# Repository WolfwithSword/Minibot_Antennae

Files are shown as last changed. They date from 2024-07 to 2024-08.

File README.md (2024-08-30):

# Minibot_Antennae
Micropython-ESP32 code for custom antennae control based on Ellie Minibot's OC's antennae. WiFi and BLE servers included for control.

Three green LEDs will be controlled by monitoring a connected LiPo battery voltage (not capacity!)

Two LEDs (one on each side) on the antennae bulbs will be PWM controlled in a fading sequence. These can be synced or toggled on/off individually via various control endpoints and services. By default on boot, they will be synced ON.

By default, WiFi Mode is enabled.

### Demo Video:

Demo Video (https://youtu.be/qy43_1V1VM8 "Demo Video")

https://youtu.be/qy43_1V1VM8 

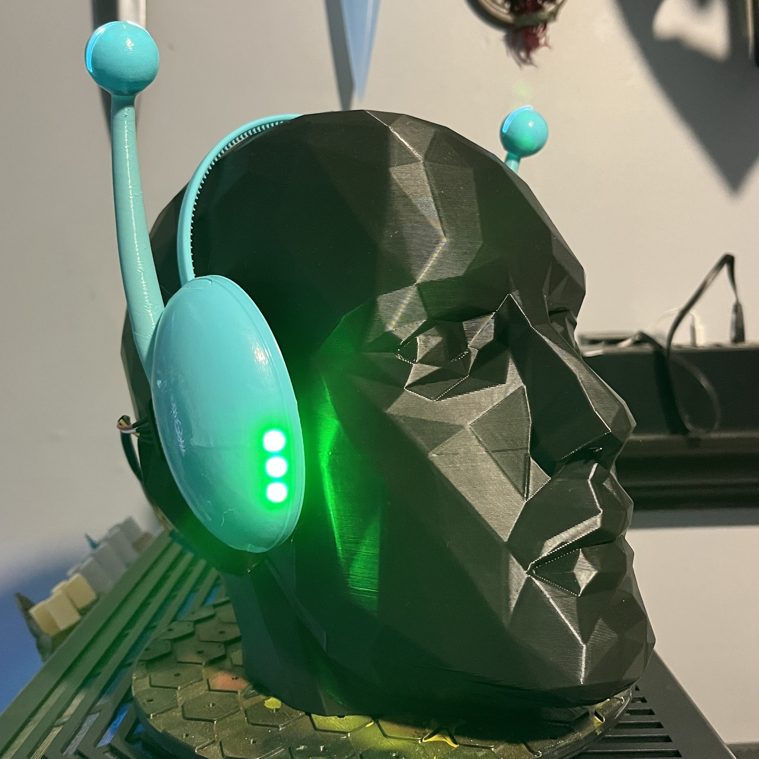
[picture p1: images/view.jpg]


# Setup

## MicroPython

- Download [esptool](https://github.com/espressif/esptool)
- Flash your board
  - Replace below command with the appropriate COM# port you plugged in to for the board 
  - `./esptool.exe --port COM# erase_flash`

- Flash with MicroPython
  - Download latest for [ESP32](https://micropython.org/download/ESP32_GENERIC/)
  - Replace COM# with yours below, as well as correct MicroPython binary downloaded
  - `./esptool.exe --chip esp32 --port COM# --baud 460800 write_flash -z 0x1000 .\ESP32_GENERIC-20240602-v1.23.0.bin`

## IDE

I recommend using [Thonny](https://github.com/thonny/thonny)

You can easily download the dependencies to the board through it.

## Dependencies

- [aioble](https://github.com/micropython/micropython-lib/tree/master/micropython/bluetooth/aioble)
  - Make sure it's the micropython lib
  
## Install

Simply save each of the files in `/src/*` to the root of the board (do not include the src folder itself). Preserve all filenames

Modify `config.json` as required. These will be the default settings on every boot.

Note: This file may be written to, but it will only ever change "mode"

## Materials

See [parts](https://github.com/WolfwithSword/Minibot_Antennae/tree/main/parts)  folder for details

You can find the files also on [Printables](https://www.printables.com/model/971520-ellie-minibot-antennae)

Note: The choice for the "FireBeetle" ESP32 controller was mostly because of the battery plug being on the side and expandability... But the fact it's a "Beetle" is a big bonus I only realized after!

Most of the design from materials, code, and components was chosen to be more accessible and customizable/tinkerable.

# Usage

## Configuration

```json
{
    "wifi": {
        "name": "minibot_AT", // Access point SSID and hostname (both in AP mode and connected to WiFi)
        "ap_password": "eBot4do8", // Access point Password. Please Change
        "max_connections": 2, // Max number of listeners allowed for the socket control server
        "port": 8080 // Port for accessing the socket control server
    },
    "ble": {
        "name": "minibot_AT", // Bluetooth device name
        "uuid": "6094935a-ba8d-4fbb-9150-904e3244610b", // BLE Service Advertised UUID
        "poll_time": 5 // How often to update BLE read-only sensors
    },
    "mode": 1, // Which mode to boot in.
    "pwm": {  // PWM pins are the Antennae bulbs only.
        "frequency": 500, // Frequency of PWM pins. 
        "delay": 0.03, // Delay between fading steps. Min 0.01.
        "off_time_multiplier": 1.2, // Multiplied by delay for time to stay fully off during PWM cycle
        "on_time_multiplier": 4.0, // Multiplied by delay for time to stay fully on during PWM cycle
        "step": 32 // Step count from 0-1024 and 1024-0 for LED brightness in between delays. Min 8
    },
    "leds": { // If true, the LED can be active.
        "green1": true, 
        "green2": true,
        "green3": true,
        "left": true,
        "right": true,
        "sync_sides": true
    },
    "poll_time": 2 // Poll time to check for battery voltage in main loop.
}
```

Mode values:
  - 0: None
    - No WiFi Socket or BLE Server active. Can only set with direct access to the board and changing the config on-board.
  - 1: WiFi
    - Enables WiFi. Will create an AP to connect to and configure a 2.4Ghz WiFi to connect to and save details for.
    - When successfully connected to a WiFi, will create a socket server at the specified port
  - 2: BLE
    - Enables the BLE server

## WiFi

### Setup

If you can't find the IP address, it will have the hostname configured as "name" in the "wifi" section of the configuration. By default, this will mean it has a hostname of `minibot_AT`, may work as `minibot_AT.local`.

When in AP mode to setup a network connection, hostname should work but if not, the setup page usually will be available at `192.168.4.1` when connected to it.

If setting up multiple, please change the hostname and maybe the password for security.

### Alternative Setup

If you don't have a second device to setup wifi with, you can manually setup WiFi connection via a file

In the root of the board, create a `wifi.dat` file and on the first line put in `SSID_NAME;SSID_PASSWORD` then add a blank empty newline after it

It must be a 2.4ghz SSID. Also for setting up multiple, you can do a new one on each line.

### Endpoints
  - GET
    - /, /data
      - Returns JSON with **battery_voltage** and **uptime_s** 
        - Example`{"battery_voltage": 4.135, "uptime_s": 155.984}`
    - /restart
      - Hard-restart the board
    - /mode/1
      - Tells you that you're dumb cause you're already in WiFi Mode
    - /mode/2
      - Switch to BLE and restart board
    - /leds/right/off
      - Turn OFF Right Antenna LED
    - /leds/right/on
      - Turn ON Right Antenna LED
    - /leds/left/off
      - Turn OFF Left Antenna LED
    - /leds/left/on
      - Turn ON Left Antenna LED
    - /leds/sync/off
      - Turn OFF Antenna LEDs (Sync)
    - /leds/sync/on
      - Turn ON Antenna LEDs (Sync)
    - All other endpoints result in HTTP 404. All previous in HTTP 200
    - /leds?delay=####
      - Set the PWM Delay to this value in seconds. Accepts floats. E.G., `?delay=1` = 1s, `?delay=0.02` = 200ms
      - Can pass in `delay=default`
      - Min value = 0.012, Max value = 10, default 0.03 (without modification)
    - /leds?steps=####
      - Set the PWM Steps to this whole number value. E.G., `?steps=32`, `?delay=0.03&steps=32`
      - Can pass in `steps=default`
      - Min value = 8, Max value = 128, default 32 (without modification)

## BLE

### Services & Characteristics
  
  - Battery Voltage: **0x2BF0**
  - Uptime Sensor (Seconds): **0x183F**
  - Switch Modes: **0x04C3**
    - 1 *uint8*: Switch to WiFi and restart board
    - All other inputs ignored
  - LED Control: **0x77DA**
    - 0 *uint8* - Turn OFF Left Antenna LED
    - 1 *uint8* - Turn ON Left Antenna LED
    - 2 *uint8* - Turn OFF Right Antenna LED
    - 3 *uint8* - Turn ON Right Antenna LED
    - 4 *uint8* - Turn OFF Antenna LEDs (Sync)
    - 5 *uint8* - Turn ON Antenna LEDs (Sync)
    - All other inputs ignored
  - Set PWM Delay: **0x77DB**
    - Milliseconds *uint16 big endian* - Set PWM Delay, accepts milliseconds, not seconds.
    - Value of 0 will set it to the default of 0.03
  - Set PWM Steps: **0x77DC**
    - Steps *uint8* - Set the PWM Steps, accepts whole numbers from 0 to 128
    - Value of 0 will set it to default of 32.
    
## Notes

You can remotely configure the PWM parameters for the bulb LEDs with WiFi or BLE. Delay will update as soon as the old delay time has elapsed so near-instant. Step will update only after a step up or step down cycle has completed for an up-cycle or down-cycle.

For example, you can adjust the delay (and steps value, but delay is preferred) remotely based on other values. One use case may be to sync entering/exiting ranges of a heart rate monitor's BPM to push different delay values, or perhaps rate ranges of any other activity.

Examples for WiFi control of PWM adjustments:

  - For a really fast cycle, I recommend `?delay=0.012&steps=64` or `?delay=0.012&steps=128` (fastest)
  - Default would be `?delay=0.03&steps=32` or `?delay=default&steps=default`

The green LEDs are not controllable as they work as battery indicators. Rather than measure current or capacity which would be more accurate, I did not have time to plot the graph to tell capacity at specific voltages as it will be battery dependant, so it is at arbitrary battery voltage amounts. A 3.7v lipo at full charge is near 5v, and will stay around 4.2v for a very long time, and when there is approx 10% and 20% ish or less remaining it will turn off the top led's. It may shut down all processing and threads shortly after reaching single-LED mode if there is not enough power left (roughly when it gets to 3.2v or below, and will full stop at under 3v). 

When there is only the last LED left one, it is possible the board will go into a deep sleep and stop all threads (no WiFi, BLE, or PWM Fades). In this mode it will keep that last LED lit for approximately 2 hours.

ALL values are reset to default when the board is restarted or switching modes. Only the value of the mode is retained after restarting, and is written to the config file.

If for whatever reason it is stuck and not connecting to WiFi or threads got stuck like from being in deepsleep and back up again after charging, just quickly disconnect the pogo connectors when it's not charging for a second. This also acts as the power switch - there is none, just unplug one side of the pogo wire.

When enabling an individual LED while Sync is on, it will disable Sync and the other LED will need to be turned on separately if you want both unsynced. Turning off Sync when sync is not enabled will do nothing. Turning on Sync will restart both lights.

When using the 1100maH battery, it will last roughly 17 hours on a full charge (charging ~1h at 2A), but can last easily 11-13 hours on fullish charge (~20-30min at 2A). Battery capacity is not measured but rather voltage levels are used as ranges to signal the three green LEDs. Just because all are lit up does not mean it is fully charged by far.

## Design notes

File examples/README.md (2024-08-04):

# Example Integrations

## Pulsoid BPM Control

`pulsoid_bpm_control.py` can be run on a desktop with python (required dependencies: `websocket-client` and `requests`)

Configuration required for a websocket that provides heartrate in terms of whole numbers, such as from Pulsoid. Comments in the code describe how you can get the websocket URL if you do not know.

Additional config may be needed for the hostname and port of the Antennae instance in **WiFi Mode**.

This script will listen for the BPM reported by the websocket connection and depending on the ranges it is in, will adjust the PWM Fade/Pulse rate of the antennae tips.

Unless modified, default settings are: 

Delay is in seconds

- BPM <= 75: Default delay (0.03), Default steps (32)
- BPM 75-90: Delay 0.02, Default steps (32)
- BPM 90-100: Delay 0.02, Steps 64
- BPM 100-120: Delay 0.12, Steps 64
- BPM 120+: Delay 0.12, Steps 128

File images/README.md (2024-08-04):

# Minibot_Antennae Media

## Completed





Demo Video (https://youtu.be/qy43_1V1VM8 "Demo Video")

## Bits n Bobs

### Models

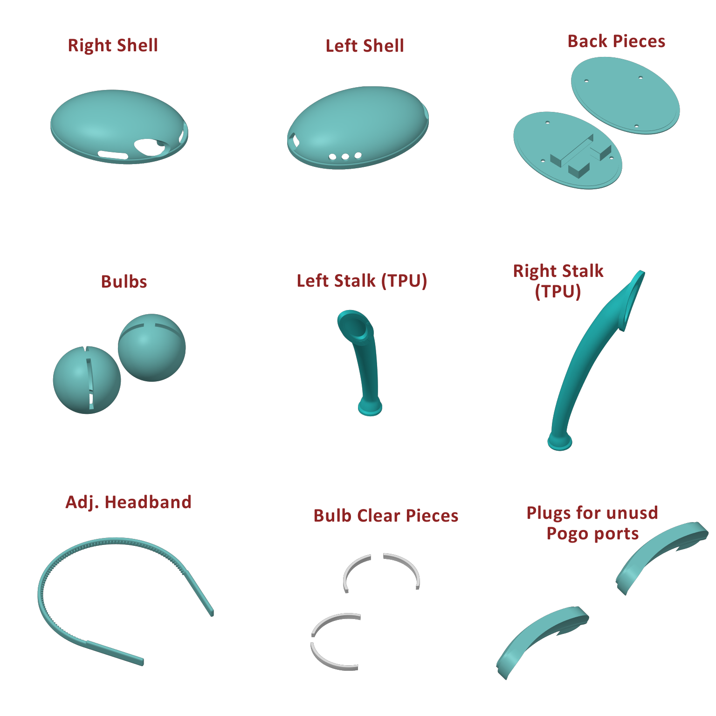
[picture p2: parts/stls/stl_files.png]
STL Images


### Headband 

Headband is adjustable with 6 holes for the screw placement, which doubles as part of the assembly. It can also rotate freely if loosened a bit, then simply tightened for a better fit.

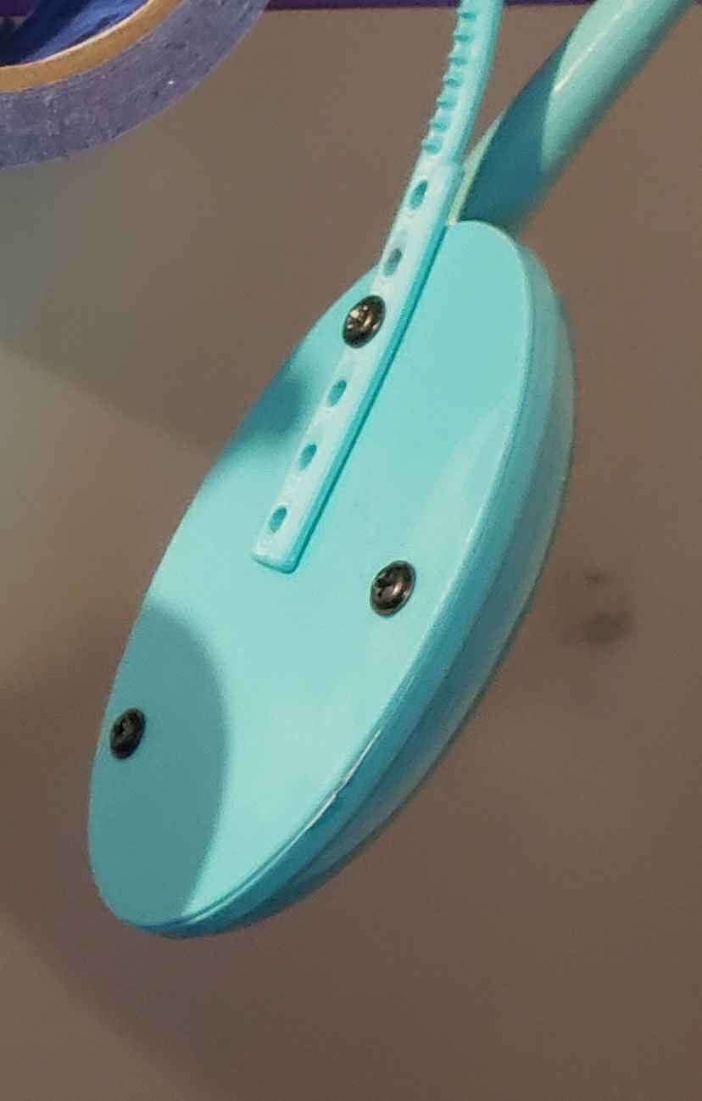
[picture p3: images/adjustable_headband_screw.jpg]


### Internals & Diagrams

The internals of the controller half (Right side) are a touch messy (I couldn't find my thinner wire, had to redo half of the solders because of broken pins while debugging a grounding wire issue, etc etc). The hot glue is purely for strain relief and to keep LEDs in place in case they wear down their friction fit.

"If it works it works" > "Hopes and dreams" 

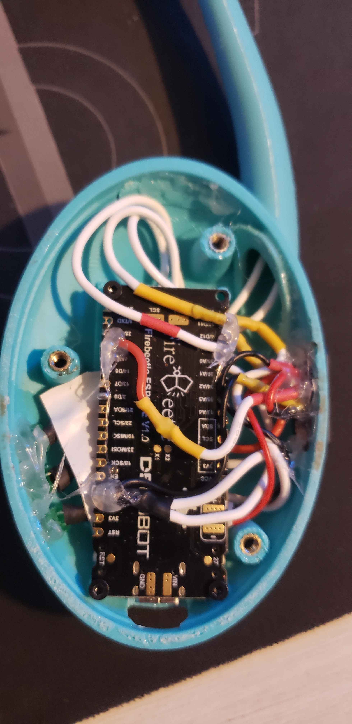
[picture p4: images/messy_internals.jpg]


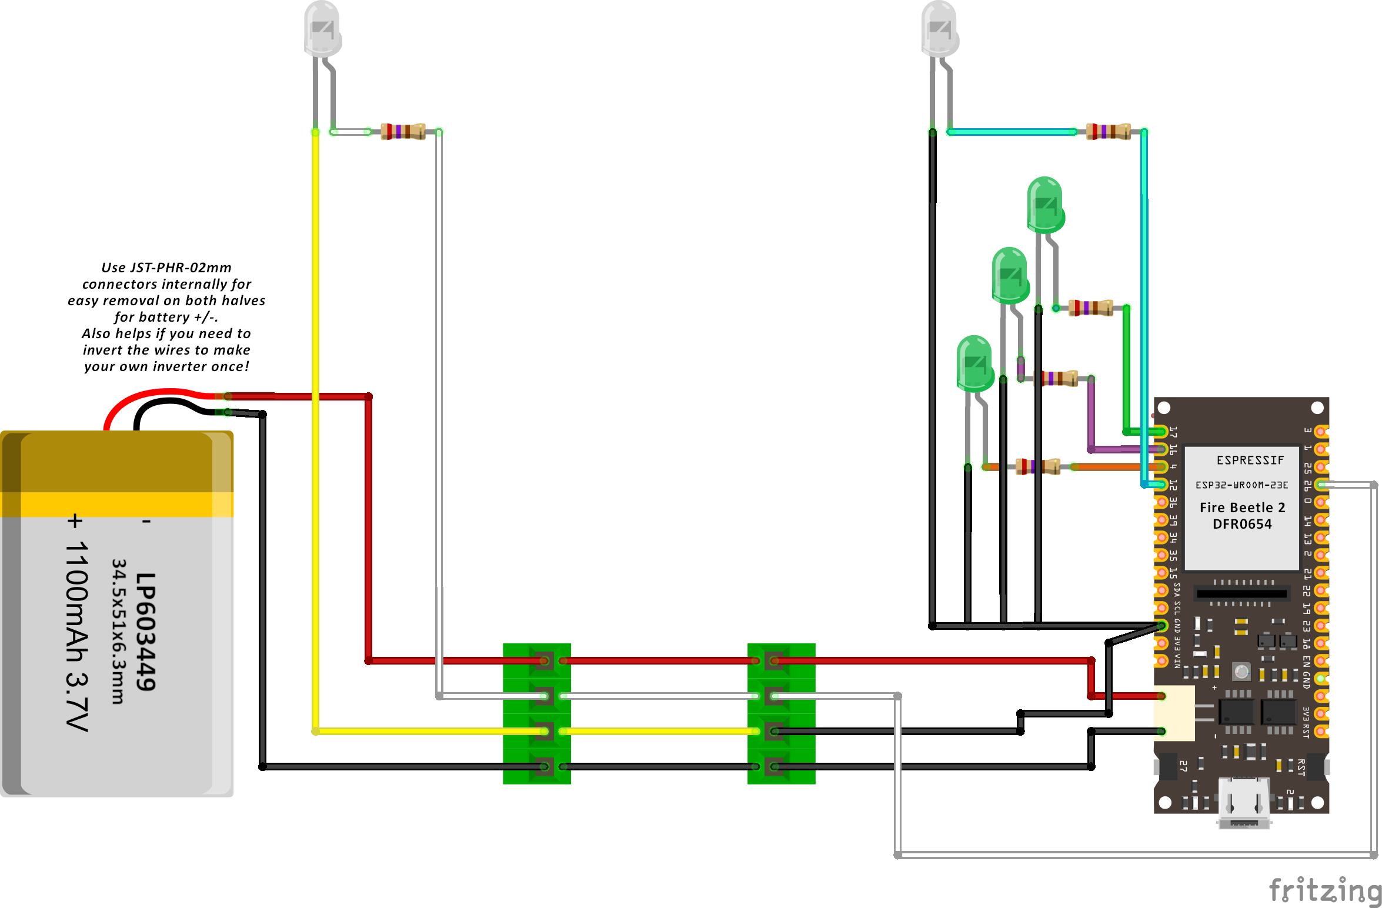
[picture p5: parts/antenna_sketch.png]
Schematic


### BLE Preview

Just a preview of some of the BLE characteristics/services for control using nRF Connect

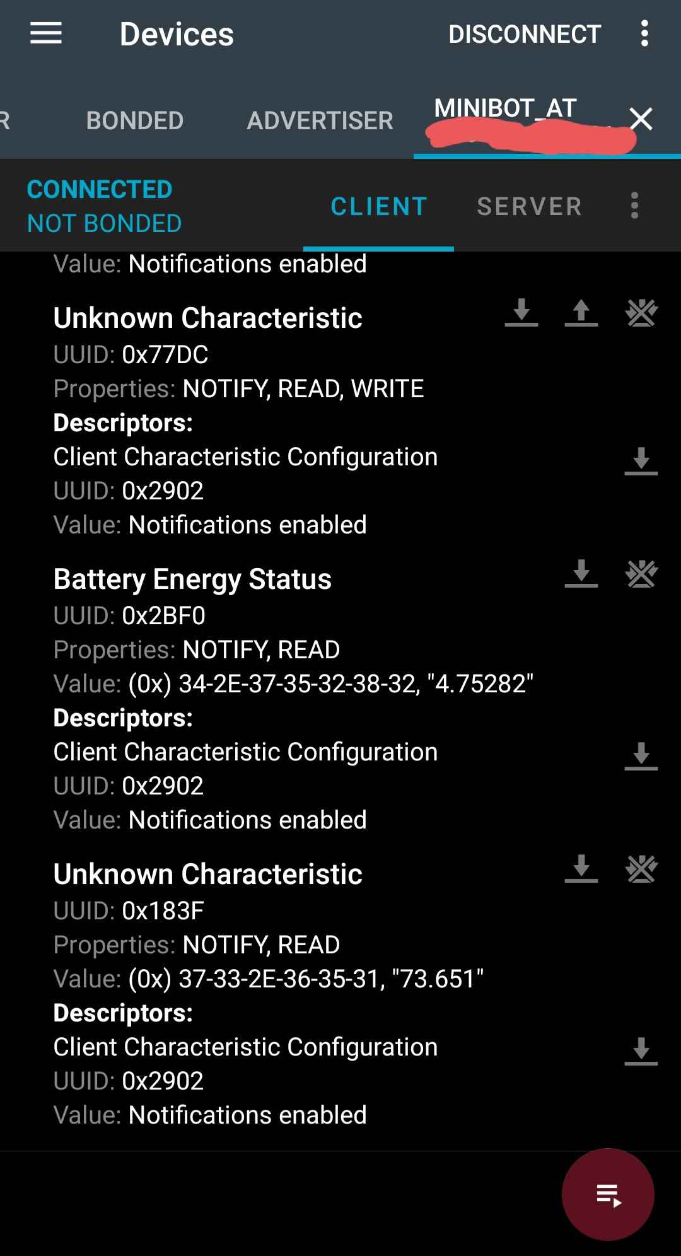
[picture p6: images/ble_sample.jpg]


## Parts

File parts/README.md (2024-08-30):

You can find the files also on [Printables](https://www.printables.com/model/971520-ellie-minibot-antennae)

# STLs

- Stalks: tpu_left_stalk.stl, tpu_right_stalk.stl
- Bulbs: abs_left_bulb, abs_right_bulb, abs_clear_left_bulb_light.stl, abs_clear_right_bulb_light.stl
- Headband: headband.stl
- Left Shell: abs_left_backing.stl, abs_left_shell.stl
- Right Shell: abs_right_backing.stl, abs_right_shell.stl
  - Note: The screw alignment for the ESP32 board is *not* perfect, despite using references. As such, when screwing in with M2 screws, may only fit 3 screws and one may be at an angle. Prioritize the front near the USB-C port.
- Misc: abs_top_plugs.stl, abs_side_plugs.stl
  - The plugs are for plugging the holes for where you do *not* use the pogo connector inserts.

# BOM

This is not my best BOM, made in rush

- ESP32 Board DFR0654. [Digikey](https://www.digikey.ca/en/products/detail/dfrobot/DFR0654/13978504),  [dfrobot](https://www.dfrobot.com/product-2195.html)
  - Any other can do, and can probably be swapped for a smaller one with a separate charge shield/circuit for battery. The one linked simply fit the best, had decent processing power and memory, and had the built in battery port and charger on the side instead of the front.
  - Chosen for expandability. If using another board, there are no guarantees as to the code working fully in case lack of processing or memory.
  - This project can use both BLE and WiFi servers, but the config does allow to disable both if you want just default settings.
- LiPo Battery
  - [3.7v 1100mAh, 34.5x51x6.3mm (WxLxH)](https://amzn.to/3zZs4OB)
  - If using the one from the link, you *MAY* need to swap the pwr and gnd leads. Make sure before hooking up to board AND before hooking up to JST port/wires. Good idea to make an inverter wire so it isn't permanent.
  - For alternatives, size the slot fits is mentioned above. If loose, please pad to make sure it does not come out during use. Capacity can be any, 1100mAh will last between 12-18 hours roughly.
- Screws
  - 4x M2 8-12mm (For ESP32, no heatset inserts, direct to plastic)
  - 2x M3 14mm 
  - 4x M3 12mm (6x if not using headband, possibly will work for all 6 anyways. Then no need for 14mm. I just used all 14mm and cut 4 of em)
- 6x M3 x4mm Heatset inserts
- Resistors
  - 5x 270ohm
- LEDs [Basic kit](https://amzn.to/4fkcopn)
  - 3x Green 5mm (Green plastic shell, so it is still green when off)
  - 2x White or Yellow (your preference) 5mm
- JST-PHR-02 Female and Male connectors (1 pair). [Example](https://amzn.to/46GCu2d)
- Wiring, Heatshrink tubes, pins etc
- Pogo connectors
  - [4Pin Wire MF 20cm](https://s.click.aliexpress.com/e/_DB3E399) To be used externally, trim if necessary
  - [4Pin Straight no-wire](https://s.click.aliexpress.com/e/_DB3E399) To be used internally
- Optional: Acetone
 - If printing in ABS, Acetone can be used to smooth it after some sanding and give a tough, glossy finish. Can vapour smooth it over time or just pour it over once and immediately remove without touching.
- Filament
  - Recommended if you don't want to paint:  [TPU](https://us.polymaker.com/products/polyflex-tpu90?variant=39574341189689&aff=333), [ABS](https://us.polymaker.com/products/polylite-abs?variant=39574342434873&aff=333) 
  - For the Clear pieces in the bulbs, can use any transparent or white filament. ABS/PLA/PETG does not matter.
- Optional: Hot glue (for securing the LEDs and possibly strain relief on some wires)
- Super Glue: (to perma attach the stalks to the shells, hot glue can work too)

# Assembly

## Wiring

See the attached image for which pins need to go where. All ground wires except from the battery can be spliced and connected to the same GND pin.

diagram

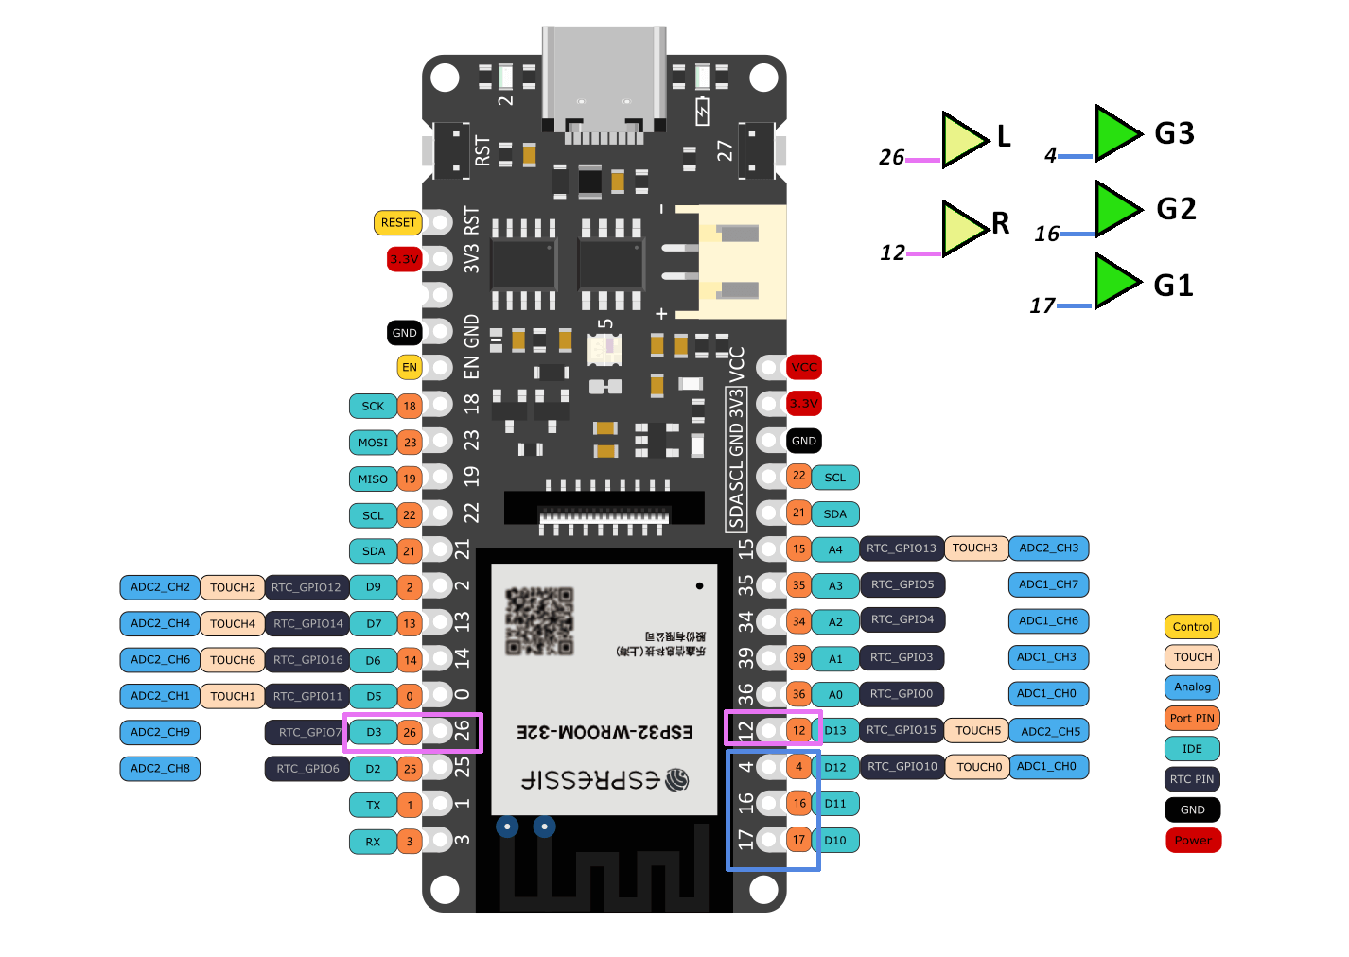
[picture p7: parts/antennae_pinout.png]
pinout


For the LED in the left antenna (where the battery is), do NOT connect the ground to the same gorund pin on the pogo connector as the battery. It will invert it (wtf). 

Use all 4 pins of the pogo connectors.

Attach each LED to a 270ohm resistor (realistically anything from 220-330ohm should be fine). 

The pogo connectors have support for 4 wires. Please make sure they line up properly. And double check the battery power/gnd to the board too.

For the PHR connectors, use the male end in the Right shell going to the pogo connector, and the female inside the Left shell going into the pogo connector (if you need to swap battery leads, can do it here or on battery itself), and plug battery into the female end, and male side into the ESP board (tight fit, may need to clip corner).

Yes I know the diagram isn't super good, made it in a hurry.

## Building

- Use short thin wires, preferably silicone for flexibility inside as it may be a tight fit. Trim the leads on the LEDs and resistors as needed. 

- Ensure the ESP32 can be screwed in (preferably route most of the wiring *under* the board) and that the backing can be screwed onto the shell still. It goes in upside down (ESP Chip, Battery port etc, will go facing the round part of the shell).

- Insert the LED for each antennae stalk with wires pre-attached through the top of the TPU stalks, then insert the stalks into the shells. They should be a smooth fit, but so superglue them at the base to make sure it is attached tightly.

- For inserting the stalks into the bulb ends, it is a *very* tight fit, recommend using tough tweezers to push it in little by little. Once in (with the LED too), pull it out slightly to make sure it is a tight fit at the end. Then insert the light-pieces into the bulb top. You can do this beforehand too and glue from the inside, or try to glue as you insert. If you used clear ABS on ABS bulbs, you can use acetone to bond them, just a light touch of it.
  - Alternatively if you cannot bend them to fit, you *can* glue the bulbs to the top of the antennae

- For the shells, if you want them smooth and glossy, sand them then treat them with acetone if printed in ABS.

- For the stalks into the antennae shells, they are not interchangable, and it will be clear which one does in which. Insert the stalk through the *inside* of each shell into the odd shaped hole. If it's the right shell, it will snugly fit. 

- Super glue the pogo connectors into the slots on the shell you choose - use plugs in the open ones and bond with superglue or acetone if ABS.

- To connect the two antennae you will need to make a POGO wire with the reverse ends that will go around the back or top depending on choice. I recommend choosing the back so it provides additional stability with the headband.

- The headband is adjustable and relies on the larger screw at the top of the back panels.

See [/images](https://github.com/WolfwithSword/Minibot_Antennae/tree/main/images) for more details.

## Tips

- The screws holding in the ESP32 may not be perfectly aligned. Try to get at least 3 in, even if they are at an angle. The front two are priority.
- The screw mounts for the shells/lids are too big to just screw into I think, hence the heatset inserts also makes them more robust for taking apart as well.
- For the small clear pieces in the bulbs, they can be clear filament, white filament, or can be omitted entirely.
- The use of a deburring tool can be helpful in making sure the hole for the USB-C port and POGO connectors fit well
- Keep in mind, ABS and ASA do shrink a bit when printed. For the Teal ABS I linked in the materials, I calculated a shrinkage of 98.9%. 
- Highly recommend gluing the pogo connectors in place when it's all done. Same for the green LEDs
- Printing a thinner wall for the TPU antennae stalks might make them more sproingly and easier to force into the bulb ends. Also printing these vertically & upsidedown should give the best surface finish, use tree supports in this case.
- Recommend quite thick walls/top/bottom layers for the shells (basically, solid walls), so there is more material to sand. If smoothing with acetone after, it also helps.
- Definitely use some JST connectors internally as easy hookups for battery stuffs.
- The headband is adjustable in sice and rotation, double using the top screw as a hinge and pin.
- Any more questions or advice or other, feel free to message me on Discord `@wolfwithsword` inbox is always open.

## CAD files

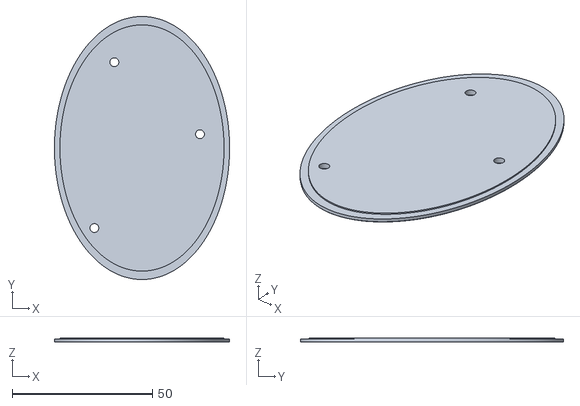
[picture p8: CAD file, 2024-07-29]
parts/stls/abs_right_backing.stl
62.4 x 93.7 x 1.60

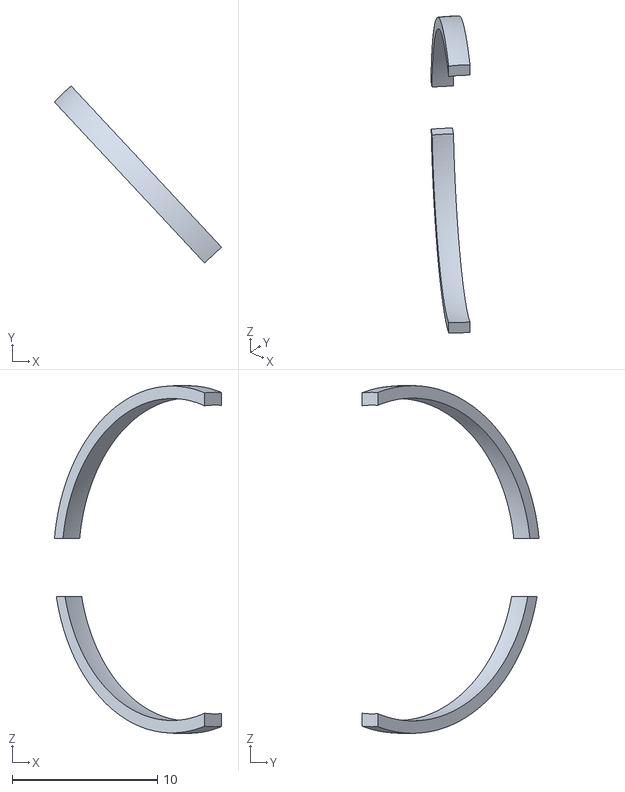
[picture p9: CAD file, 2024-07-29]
parts/stls/abs_clear_left_bulb_light.stl
11.5 x 12.2 x 24.0

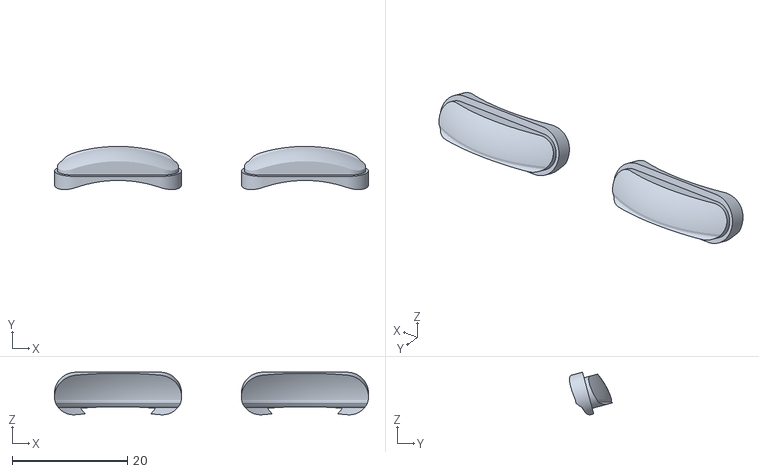
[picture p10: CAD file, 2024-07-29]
parts/stls/abs_top_plugs.stl
54.6 x 7.50 x 7.41

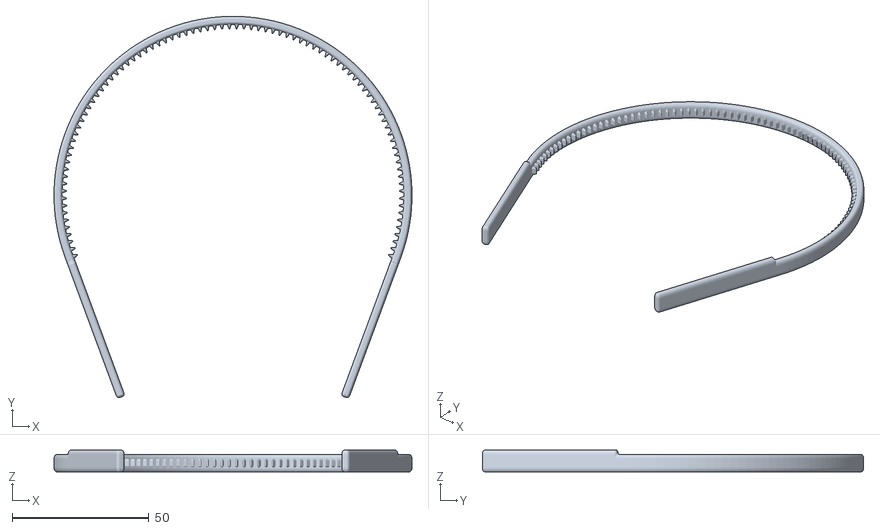
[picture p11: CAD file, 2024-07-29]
parts/stls/headband.stl
131.0 x 139.5 x 8.00

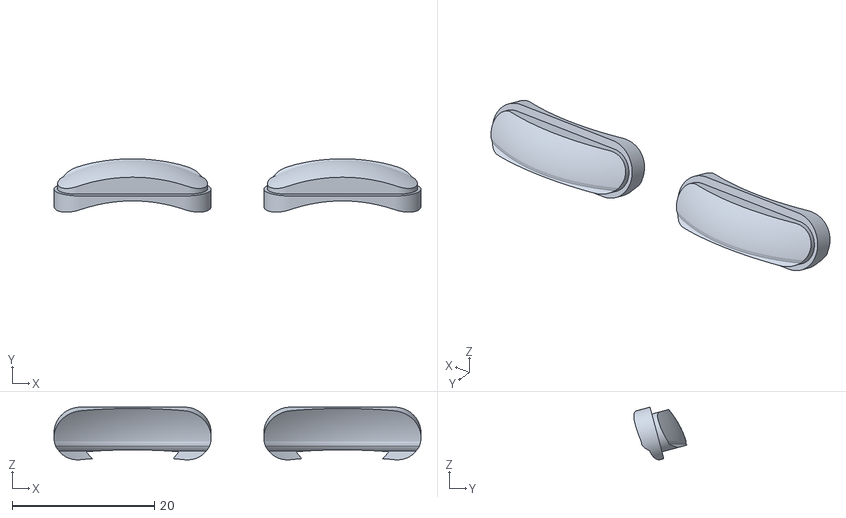
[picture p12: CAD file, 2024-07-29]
parts/stls/abs_side_plugs.stl
51.6 x 7.50 x 7.41

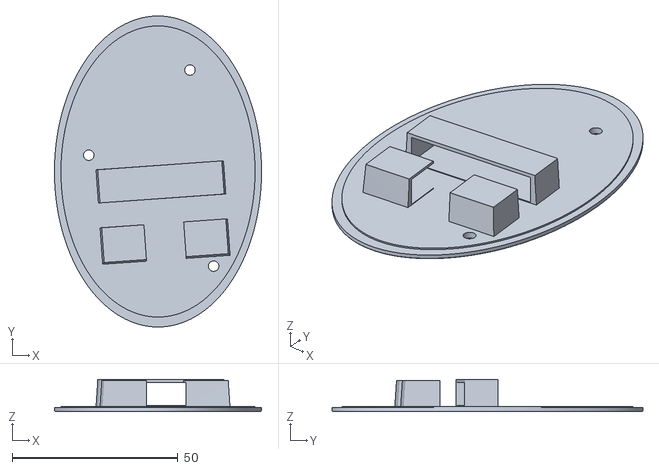
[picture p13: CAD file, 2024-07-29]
parts/stls/abs_left_backing.stl
62.4 x 93.7 x 9.72

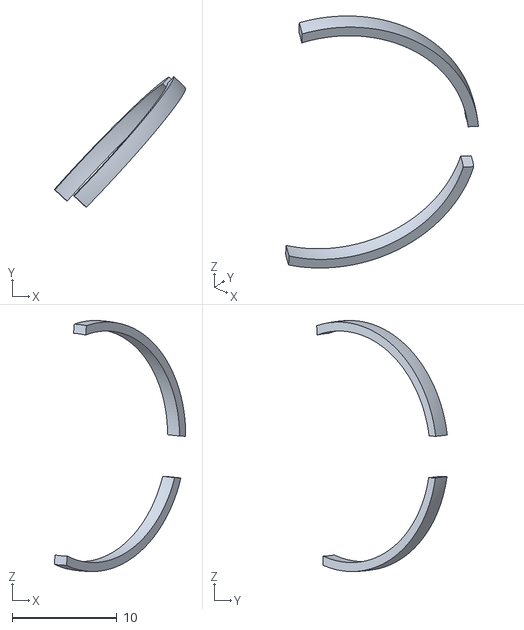
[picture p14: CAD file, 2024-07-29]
parts/stls/abs_clear_right_bulb_light.stl
12.6 x 12.5 x 24.0

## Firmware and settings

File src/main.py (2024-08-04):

from micropython import const

try:
    import utime as time
except:
    import time

import _thread as th

from pinmgr import PinManager
from utils import Utils, _USE_WIFI, _USE_BLE, _USE_NONE
from wificonn import WiFiConn
from bleconn import BLEConn

try:
    import uasyncio as asyncio
except:
    import asyncio

import aioble, bluetooth


import gc
gc.collect()
#print(gc.mem_free())

_utils = Utils()

print(_utils.config)

#############
MODE = _utils.config.get('mode', _USE_WIFI)
#############

print("Starting...")

# g1 = Bottom Green
# g2 = Middle Green
# g3 = Top Green
# left = Left Antennae bulb
# right = Right Antennae bulb
# bat_pin = Internal Battery Voltage ADC
pins = PinManager(g1=17, g2=16, g3=4, left=26, right=12, bat_pin=34, pwm_pins=[26,12], _utils=_utils)


_data = {
    "battery_voltage": 0.0,
}

time.sleep(1)

POLL_TIME = _utils.config.get('poll_time')
def main_monitor():
    while True:
        pins.green_led_battery_controller()
        time.sleep(POLL_TIME)
        #print(gc.mem_free())
        if (gc.mem_free() < 32000):
            gc.collect()
        if (gc.mem_free() < 7500):
            print("RESTARTING. LOW MEMORY")
            _utils.restart()
            
####################

th.start_new_thread(main_monitor, [])
time.sleep(1)
pins.start_sync_lights()
    
if MODE == _USE_WIFI:
    wifi_conn = WiFiConn(pins=pins, _utils=_utils)
    th.start_new_thread(wifi_conn.run, [])
elif MODE == _USE_BLE:
    ble_conn = BLEConn(pins=pins, _utils=_utils)
    asyncio.run(ble_conn.run())

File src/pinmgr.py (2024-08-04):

from machine import Pin, ADC, PWM
import _thread as th
from utils import Utils
try:
    import utime as time
except:
    import time
import gc

class PinManager():
    
    def __init__(self, g1: int, g2: int, g3: int, left: int, right: int, bat_pin: int,
                 pwm_pins: list, _utils: Utils):
        
        self._config = _utils.config
        
        self.battery_pin = ADC(bat_pin)
        self.battery_pin.atten(ADC.ATTN_11DB)
        
        self.green_1 = Pin(g1, Pin.OUT)
        self.green_2 = Pin(g2, Pin.OUT)
        self.green_3 = Pin(g3, Pin.OUT)
        
        self.left_led = Pin(left, Pin.OUT)
        self.right_led = Pin(right, Pin.OUT)

        self.left_led_pwm = None
        self.right_led_pwm = None
        
        self.set_delay(self._config.get("pwm", {}).get('delay', 0.01))
        self.set_steps(self._config.get("pwm", {}).get('step', 8))
        self.on_time_mult = self._config.get("pwm", {}).get('on_time_multiplier', 4.0)
        self.off_time_mult = self._config.get("pwm", {}).get('off_time_multiplier', 1.2)
        
        self.leds = self._config.get('leds', {})
        # Direct var references fix most of the mem leak un _run methods
        self.right_led_enabled = self.leds['right']
        self.left_led_enabled = self.leds['left']
        self.sync_leds_enabled = self.leds['sync_sides']
        self.g1_enabled = self.leds['green1']
        self.g2_enabled = self.leds['green2']
        self.g3_enabled = self.leds['green3']
        
        for p in pwm_pins:
            if p == left:
                self.left_led_pwm = PWM(self.left_led)
            elif p == right:
                self.right_led_pwm = PWM(self.right_led)
                
        pwm_freq = self._config.get("pwm", {}).get("frequency", 5000)
        
        if self.left_led_pwm:
            self.left_led_pwm.init(freq=pwm_freq, duty=0)
        if self.right_led_pwm:
            self.right_led_pwm.init(freq=pwm_freq, duty=0)
        
        self.pwm_pin_d = {
            "left_pwm": self.left_led_pwm,
            "right_pwm": self.right_led_pwm
        }
        
        self.init_off()
        
    def init_off(self):
        states = {
            "g1": 0,
            "g2": 0,
            "g3": 0,
            "left": 0,
            "right": 0,
            "left_pwm": 0,
            "right_pwm": 0
        }

        self.set_pins(states)
        states = None
        del states
        
    def set_pins(self, status:dict):
        if not self.leds:
            return
        if status.get('g1') is not None and (self.g1_enabled or status.get('g1') == 0):
            self.green_1.value(status.get('g1'))
        if status.get('g2') is not None and (self.g2_enabled or status.get('g2') == 0):
            self.green_2.value(status.get('g2'))
        if status.get('g3') is not None and (self.g3_enabled or status.get('g3') == 0):
            self.green_3.value(status.get('g3'))
        if status.get('left') is not None and (self.left_led_enabled or status.get('left') == 0):
            self.left_led.value(status.get('left'))
        if status.get('right') is not None and (self.right_led_enabled  or status.get('right') == 0):
            self.right_led.value(status.get('right'))
        
        if status.get('left_pwm') is not None:
            if self.left_led_pwm and (self.left_led_enabled or status.get('left_pwm') == 0):
                self.left_led_pwm.duty(status.get('left_pwm'))
        if status.get('right_pwm') is not None:
            if self.right_led_pwm and (self.right_led_enabled or status.get('right_pwm') == 0):
                self.right_led_pwm.duty(status.get('right_pwm'))
        status = None
        del status
        
        
    def get_battery_voltage(self):
        if self.battery_pin:
            return ((4.2*self.battery_pin.read())/4095)*2
        return 0

    
    def green_led_battery_controller(self):
        bat_voltage = self.get_battery_voltage()
        if bat_voltage == 0:
            self.init_off()
            return

        if self.green_1 and self.green_1.value() != 1:
            self.set_pins({"g1": 1})
            
        if bat_voltage >= 3.44:
            if self.green_2.value() != 1:
                time.sleep(0.5)
                self.set_pins({"g2": 1})
        else:
            if self.green_2.value() != 0:
                self.set_pins({"g2": 0})
            
        if bat_voltage >= 3.60:
            if self.green_3.value() != 1:
                time.sleep(0.5)
                self.set_pins({"g3": 1})
        else:
            if self.green_3.value() != 0:
                self.set_pins({"g3": 0})


    def start_fade_loop(self, pwm_pins: list, run):
        # PWM Fade a pin, after initial delay
        for p in pwm_pins:
            p.duty(0)
        time.sleep(0.75)

        step = self.steps
        if step < 8:
            step = 8
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

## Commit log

2024-07-29 Initial commit
    Initial project setup. TODO: Add STLs, circuit diagram and BOM
2024-07-29 Add models, update code
    Add pwm control endpoints, add models, update readmes
    [abs_clear_left_bulb_light.stl, abs_clear_right_bulb_light.stl, abs_left_backing.stl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]
2024-07-31 Update on/off times for PWM
    Fix code that I accidentally overwrote
    [bleconn.py, main.py, pinmgr.py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]
2024-07-31 Add sample for pulsoid or websocket control
2024-08-03 Add debug battery adc to wifi data
2024-08-04 Fix sync and individual led logic and threading
    [bleconn.py, main.py, pinmgr.py]
2024-08-10 Add tips to parts-assembly readme
2024-08-11 Add printables link
2024-08-30 Add more assembly instructions
